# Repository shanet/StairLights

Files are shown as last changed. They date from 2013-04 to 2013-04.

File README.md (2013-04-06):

StairLights
===

### shane tully
### shanetully.com

StairLights is an Arduino-based LED stair way lighting project. It uses an Arduino, two IR transmitters, two IR recievers, and a strand of individually controllable LEDs to display light patterns on stairs when a person is walking up or down them.

Demo of it in action: http://www.youtube.com/watch?v=21KKr8hQo5A

## Parts

* Arduino Uno R3 (http://www.adafruit.com/products/50)
* Adafruit 36mm 12V LEDs (http://www.adafruit.com/products/683)
* 12V 5A power supply for the LEDs (https://www.adafruit.com/products/352)
* 2.1mm barallel plug adapter (https://www.adafruit.com/products/368)
* Two IR transmitters (https://www.sparkfun.com/products/10732)
* Two IR receivers (https://www.sparkfun.com/products/10266)
* About 150ft of 22 AWG hook-up wire (https://www.adafruit.com/products/290)

## Installation

A circuit diagram is provided as a png and a Fritzing file. Missing from the diagram is the external power supply connected to the LED strand.

Once everything is wired up, load the sketch on the Arduino like any other sketch.

## More Info

A much more detailed write-up is available on my blog at http://shanetully.com/2013/04/stairlights-an-arduino-based-led-stair-lighting-project/.

## License
Copyright (C) 2013 Shane Tully

This program is free software: you can redistribute it and/or modify
it under the terms of the GNU Lesser General Public License as published by
the Free Software Foundation, either version 3 of the License, or
(at your option) any later version.

This program is distributed in the hope that it will be useful,
but WITHOUT ANY WARRANTY; without even the implied warranty of
MERCHANTABILITY or FITNESS FOR A PARTICULAR PURPOSE.  See the
GNU Lesser General Public License for more details.

You should have received a copy of the GNU Lesser General Public License
along with this program.  If not, see <http://www.gnu.org/licenses/>.

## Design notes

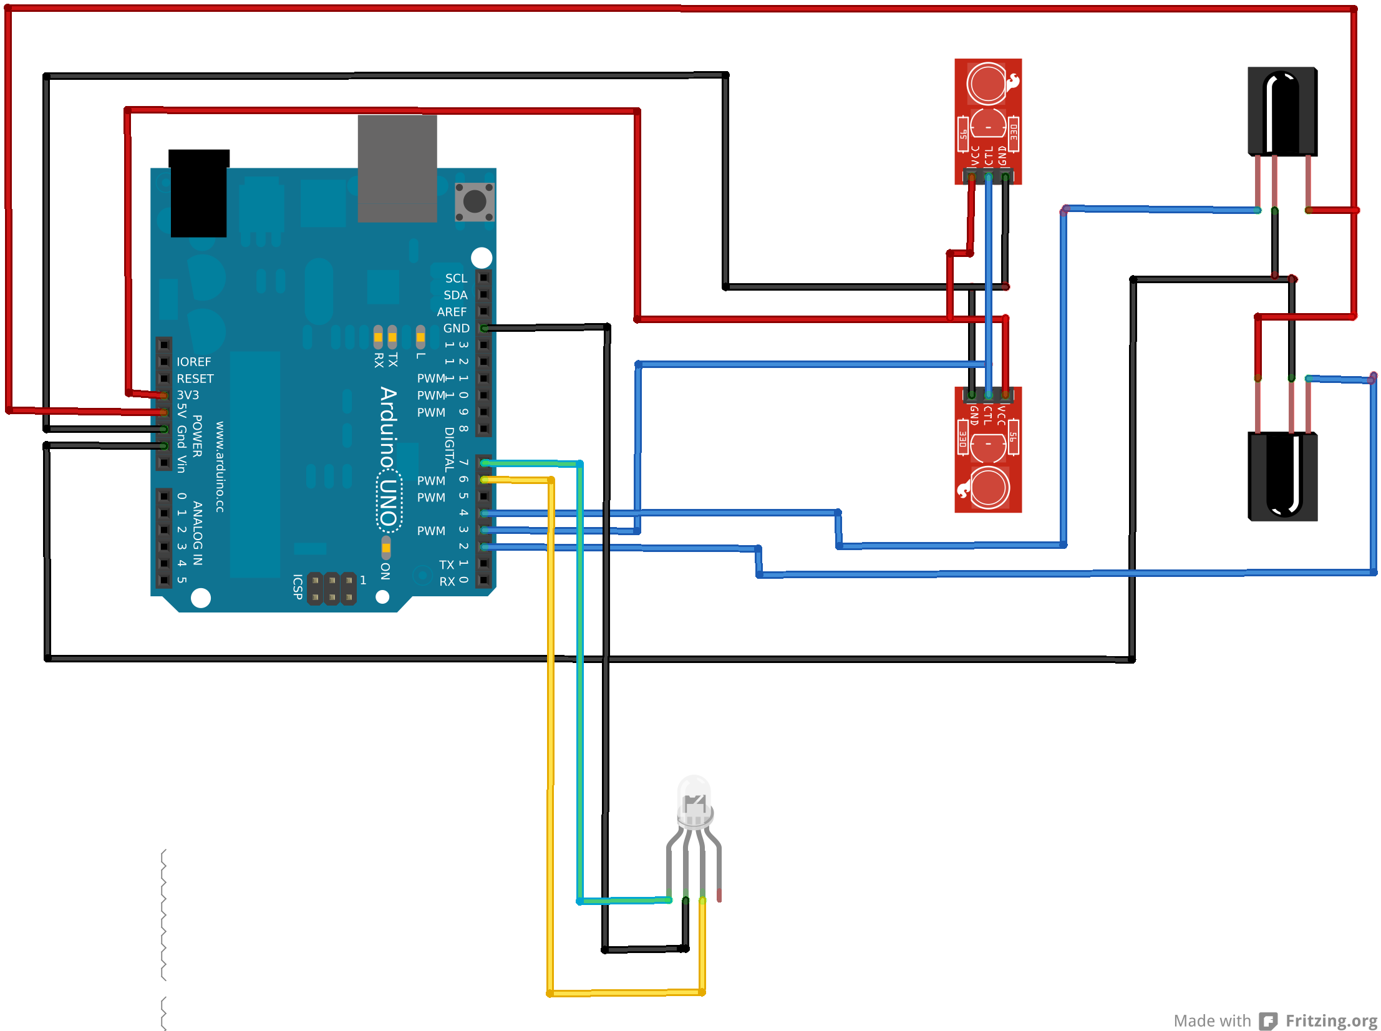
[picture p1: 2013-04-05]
stairlights_circuit_diagram.png

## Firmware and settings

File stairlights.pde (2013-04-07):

// StairLights
// shane tully (shane@shanetully.com)
// shanetully.com

// GitHub repo: https://github.com/shanet/StairLights
// Makes use of the Adafruit WS2801 LED library
// https://github.com/adafruit/Adafruit-WS2801-Library
// Code snippits taken from the Arduino IRremote library
// https://github.com/shirriff/Arduino-IRremote

// Copyright (C) 2013 Shane Tully

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
#include "SPI.h"
#include "Adafruit_WS2801.h"

#define IR_DETECT_UPSTAIRS_PIN     2
#define IR_DETECT_DOWNSTAIRS_PIN   4

#define LIGHTS_DATA_PIN  6 // Yellow wire
#define LIGHTS_CLOCK_PIN 7 // Green wire

// IR transmit frequency. You probably don't want to change this.
#define IR_KHZ     38

// Number of pixels (LEDs) in the strand
#define NUM_PIXELS 20

// Color options
#define MULTI  0
#define RED    1
#define ORANGE 2
#define YELLOW 3
#define GREEN  4
#define BLUE   5
#define PURPLE 6

// Rotation speed options
#define ROT_NONE      0
#define ROT_VERY_SLOW 1
#define ROT_SLOW      2
#define ROT_NORMAL    3
#define ROT_FAST      4
#define ROT_VERY_FAST 5

// Fade speed options
#define FADE_NONE      0
#define FADE_VERY_SLOW 1
#define FADE_SLOW      2
#define FADE_NORMAL    3
#define FADE_FAST      4
#define FADE_VERY_FAST 5

// Rotation direction options
#define ROT_CW  0
#define ROT_CCW 1

// Shadow length options
#define SDW_NONE       0
#define SDW_VERY_SMALL 1
#define SDW_SMALL      2
#define SDW_NORMAL     3
#define SDW_LONG       4
#define SDW_VERY_LONG  5

// Direction of the light pattern
#define UP   0
#define DOWN 1

#define FADE_INCOMPLETE 0
#define FADE_COMPLETE   1

// Macros for the IR transmitters. See the enable IR transmitters function.
#define TIMER_PWM_PIN        3
#define TIMER_ENABLE_PWM     (TCCR2A |= _BV(COM2B1))
#define TIMER_DISABLE_INTR   (TIMSK2 = 0)

Adafruit_WS2801 lights = Adafruit_WS2801((uint16_t)NUM_PIXELS, (uint8_t)LIGHTS_DATA_PIN, (uint8_t)LIGHTS_CLOCK_PIN, (uint8_t)WS2801_GRB);

void setup() {
   pinMode(IR_DETECT_UPSTAIRS_PIN, INPUT);
   pinMode(IR_DETECT_DOWNSTAIRS_PIN, INPUT);

   enableIrTransmitters(IR_KHZ);

   lights.begin();

   randomSeed(analogRead(0));

   // Wait a second to prevent "phantom" signals from the IR receivers on start up
   delay(1000);
}

void loop() {
   if(!digitalRead(IR_DETECT_UPSTAIRS_PIN)) {
      show_stair_lights(DOWN);
   } else if(!digitalRead(IR_DETECT_DOWNSTAIRS_PIN)) {
      show_stair_lights(UP);
   }
}


void show_stair_lights(int direction) {
   // Pick a random light pattern
   int pattern = random(0, 6);

   switch(pattern) {
      case 0:
         basic_color(direction);
         break;
      case 1:
         rainbow_fade(direction, 75);
         break;
      case 2:
         rainbow_cycle(direction, 4, 20);
         break;
      case 3:
         colorswirl(direction, 10000);
         break;
      case 4:
         trail(direction, 7, 10, 50);
         break;
      case 5:
         stack(direction, 50);
         break;
   }
}


void basic_color(int direction) {
   unsigned char red   = 0;
   unsigned char green = 0;
   unsigned char blue  = 0;

   get_random_color(&red, &green, &blue);

   int steps      = 10;
   int delay_time = 5;
   run_colors(0, red, 0, green, 0, blue, steps, direction, delay_time);

   delay(10000);

   // Fade out more slowly
   steps      = 100;
   delay_time = 40;
   run_colors(red, 0, green, 0, blue, 0, steps, direction, delay_time);
}


void run_colors(unsigned char old_red, unsigned char new_red, unsigned char old_green, unsigned char new_green, 
               unsigned char old_blue, unsigned char new_blue, int steps, int direction, int delay_time) {
   int start_pixel;
   int end_pixel;
   get_start_and_end_pixels(direction, &start_pixel, &end_pixel);

   float red_step   = (float)(new_red   - old_red)   / steps;
   float green_step = (float)(new_green - old_green) / steps;
   float blue_step  = (float)(new_blue  - old_blue)  / steps;

   if(direction == UP) start_pixel++;

   for(int i=start_pixel; (direction == UP ? i>=end_pixel : i<end_pixel); (direction == DOWN ? i+=2 : i-=2)) {
      float cur_red   = old_red;
      float cur_green = old_green;
      float cur_blue  = old_blue;

      for(int j=0; j<steps; j++) {
         cur_red   += red_step;
         cur_green += green_step;
         cur_blue  += blue_step;

         lights.setPixelColor(i, (unsigned char)cur_red, (unsigned char)cur_green, (unsigned char)cur_blue);
         lights.setPixelColor(i+1, (unsigned char)cur_red, (unsigned char)cur_green, (unsigned char)cur_blue);
         lights.show();

         delay(6);
      }

      delay(delay_time);
   }
}


void fade_colors(unsigned char old_red, unsigned char new_red, unsigned char old_green, unsigned char new_green, 
                unsigned char old_blue, unsigned char new_blue, int steps, int delay_time) {
   float red_step   = (float)(new_red   - old_red)   / steps;
   float green_step = (float)(new_green - old_green) / steps;
   float blue_step  = (float)(new_blue  - old_blue)  / steps;

   float cur_red   = old_red;
   float cur_green = old_green;
   float cur_blue  = old_blue;

   for(int i=0; i<steps; i++) {
      cur_red   += red_step;
      cur_green += green_step;
      cur_blue  += blue_step;

      for(int j=0; j<lights.numPixels(); j++) {
         lights.setPixelColor(j, (unsigned char)cur_red, (unsigned char)cur_green, (unsigned char)cur_blue);
      }

      lights.show();

      delay(delay_time);
   }
}


void rainbow_fade(int direction, int delay_time) {
   float fade_constant = 0;
   int shadow_position = get_initial_shadow_position(direction);

   int start_pixel;
   int end_pixel;
   get_start_and_end_pixels(direction, &start_pixel, &end_pixel);

   // 3 cycles of all 256 colors in the color_wheel
   for(int i=0; i<256; i++) {
      // Fade in and out on the first and last 50 cycles
      if(i < 50) {
         fade_constant += .02;
      } else if(i > 205) {
         fade_constant -= .02;
      }

      // Show the pixels one by one up/down the stairs during fading
      if(i < lights.numPixels()) {
         if(direction == UP) {
            shadow_position--;
         } else {
            shadow_position++;
         }
      }

      for(int j=start_pixel; (direction == UP ? j>=end_pixel : j<end_pixel); (direction == DOWN ? j++ : j--)) {
         float local_fade_constant = fade_constant;
         if(i < lights.numPixels() && (direction == DOWN ? j > shadow_position : j < shadow_position)) {
            local_fade_constant = 0;
         }

         lights.setPixelColor(j, color_wheel((i + j) % 255, local_fade_constant));
      }  

      lights.show();

      delay(delay_time);
   }
}


void rainbow_cycle(int direction, int num_cycles, int delay_time) {
   float fade_constant = 0;
   int shadow_position = get_initial_shadow_position(direction);

   int start_pixel;
   int end_pixel;
   get_start_and_end_pixels(direction, &start_pixel, &end_pixel);

   for(int i=0; i<256*num_cycles; i++) {
      // Fade in and out on the first and last 50 cycles
      if(i < 50) {
         fade_constant += .02;
      } else if(i > 256*num_cycles - 51) {
         fade_constant -= .02;
      }

      // Show the pixels one by one up/down the stairs during fading
      if(i < lights.numPixels()) {
         if(direction == UP) {
            shadow_position--;
         } else {
            shadow_position++;
         }
      }

      for(int j=0; j<lights.numPixels(); j++) {
         // we use each pixel as a fraction of the full 96-color color_wheel
         // (thats the i / lights.numPixels() part)
         // Then add in j which makes the colors go around per pixel
         // the % 96 is to make the color_wheel cycle around
         float local_fade_constant = fade_constant;
         if(i < lights.numPixels() && (direction == DOWN ? j > shadow_position : j < shadow_position)) {
            local_fade_constant = 0;
         }

         uint32_t color = color_wheel(((j * 256 / lights.numPixels()) + i) % 256, local_fade_constant);
         lights.setPixelColor(j, color);
      }

      lights.show();

      if(i < lights.numPixels()) {
         delay(delay_time*4);
      } else {
         delay(delay_time);
      }
   }
}


void trail(int direction, int trail_len, int cycles, int delay_time) {
   unsigned char red   = 0;
   unsigned char green = 0;
   unsigned char blue  = 0;
   get_random_color(&red, &green, &blue);

   int start_pixel;
   int end_pixel;
   get_start_and_end_pixels(direction, &start_pixel, &end_pixel);

   // Generate the constants to multiply the brightness by for the trail
   float trail_constants[trail_len];
   trail_constants[0] = (float)1/trail_len;
   for(int i=2; i<=trail_len; i++) {
      trail_constants[i-1] = trail_constants[i-2] + (float)1/trail_len;
   }

   for(int i=0; i<cycles; i++) {
      // Pick a new random color on each cycle
      unsigned char red;
      unsigned char green;
      unsigned char blue;
      get_random_color(&red, &green, &blue);

      for(int j=start_pixel; (direction == UP ? j>=end_pixel-trail_len : j<=end_pixel+trail_len); (direction == DOWN ? j++ : j--)) {
         // Set all non-trail pixels to 0
         for(int k=0; k<lights.numPixels(); k++) {
            lights.setPixelColor(k, 0, 0, 0);
         }

         // Set the trail pixels to the appropriate color
         int k = j-trail_len;
         if(direction == UP) {
            k = j+trail_len;
         }
         for(int l=0; (direction == UP ? k>j-trail_len : k<j+trail_len); (direction == UP ? k-- : k++), l++) {
            lights.setPixelColor(k, red*trail_constants[l], green*trail_constants[l], blue*trail_constants[l]);
         }

         lights.show();

         delay(delay_time);
      }
   }

   clear_lights();
}


void stack(int direction, int delay_time) {
   uint32_t color = get_random_color();

   show_stack(direction, color, delay_time);

   delay(10000);

   show_destack(direction, color, delay_time);

   clear_lights();
}


void show_stack(int direction, uint32_t color, int delay_time) {
   // The start and end pixels are reversed from the other patterns so don't use
   // the get start and end pixels function
   int start_pixel;
   int end_pixel;
   int target;
   switch(direction) {
      case UP:
         start_pixel = 0;
         end_pixel   = lights.numPixels();
         target      = lights.numPixels() - 1;
         break;
      case DOWN:
         start_pixel = lights.numPixels() - 1;
         end_pixel   = 0;
         target      = 0;
         break;
   }

   for(int i=start_pixel; (direction == UP ? i<end_pixel : i>end_pixel); (direction == DOWN ? i-=2 : i+=2)) {
      int cur_stair = lights.numPixels() - 1;
      if(direction == UP) {
         cur_stair = 0;
      }
   
      while((direction == UP ? cur_stair < target : cur_stair > target)) {
         // Turn off all pixels below the target level
         for(int j=start_pixel; (direction == UP ? j<target : j>target); (direction == DOWN ? j-- : j++)) {
            lights.setPixelColor(j, 0);
         }

         // Set the current pixel and the next pixel to the given color
         lights.setPixelColor(cur_stair, color);
         if(direction == UP) {
            lights.setPixelColor(cur_stair+1, color);
         } else {
            lights.setPixelColor(cur_stair-1, color);
         }
         lights.show();
         
         if(direction == UP) {
            cur_stair += 2;
         } else {
            cur_stair -= 2;
         }

         delay(delay_time);
      }

      if(direction == UP) {
         target -= 2;
      } else {
         target += 2;
      }
   }
}


void show_destack(int direction, uint32_t color, int delay_time) {
   int start_pixel;
   int end_pixel;
   get_start_and_end_pixels(direction, &start_pixel, &end_pixel);

   int target = lights.numPixels()-1;
   if(direction == UP) {
      target = 0;
   }

   for(int i=start_pixel; (direction == UP ? i>end_pixel : i<end_pixel); (direction == DOWN ? i+=2 : i-=2)) {
      int cur_stair = target;
   
      while((direction == UP ? cur_stair >= end_pixel : cur_stair <= end_pixel)) {
         // Turn off all pixels above the target level
         for(int j=end_pixel; (direction == UP ? j<target+2 : j>target-2); (direction == DOWN ? j-- : j++)) {
            lights.setPixelColor(j, 0);
         }

         // Set the current pixel and the next pixel to the given color
         lights.setPixelColor(cur_stair, color);
         if(direction == UP) {
            lights.setPixelColor(cur_stair+1, color);
         } else {
            lights.setPixelColor(cur_stair-1, color);
         }
         lights.show();
         
         if(direction == UP) {
            cur_stair -= 2;
         } else {
            cur_stair += 2;
         }

         delay(delay_time);
      }

      if(direction == UP) {
         target += 2;
      } else {
         target -= 2;
      }
   }
}


void colorswirl(int direction, int run_time) {
   // These are fun to play with to generate different effects
   // See the macros defined at the top of the file for options
   int color           = MULTI;
   int rotation_speed  = ROT_VERY_FAST;
   int rotation_dir    = ROT_CCW;
   int shadow_length   = SDW_VERY_SMALL;
   int fade_speed      = FADE_NONE;

   // Rotate the other way if going down the stairs
   if(direction == DOWN) {
      rotation_dir = ROT_CW;
   }

   unsigned long start_time = millis();

   // Fade in
   while(get_colorswirl_data(1, 0, color, rotation_speed, rotation_dir, shadow_length, fade_speed) != FADE_COMPLETE) {
      lights.show();
   }

   // Main loop
   // Run for the specified time
   while(start_time + run_time > millis()) {
      get_colorswirl_data(0, 0, color, rotation_speed, rotation_dir, shadow_length, fade_speed);
      lights.show();
   }

   // Fade out
   while(get_colorswirl_data(0, 1, color, rotation_speed, rotation_dir, shadow_length, fade_speed) != FADE_COMPLETE) {
      lights.show();
   }
}


int get_colorswirl_data(int fade_in, int fade_out, int color, int rotation_speed, int rotation_dir, int shadow_length, int fade_speed) {
   static float shadow_position = 0;
   static float light_position  = 0;
   static int hue               = 0;
   static float fade_constant   = 0;

   int brightness;
   unsigned char red;
   unsigned char green;
   unsigned char blue;

   shadow_position = light_position;

   for(int i=0; i<lights.numPixels(); i++) {
      get_led_color(color, &red, &green, &blue, hue);

      // Resulting hue is multiplied by brightness in the
      // range of 0 to 255 (0 = off, 255 = brightest).
      // Gamma corrrection (the 'pow' function here) adjusts
      // the brightness to be more perceptually linear.
      brightness = (shadow_length != SDW_NONE || rotation_speed != ROT_NONE) ? (int)(pow(0.5 + sin(shadow_position) * 0.5, 3.0) * 255.0) : 255;

      // If fading in or out, reduce the brightness by the fade constant
      if(fade_in || fade_out) {
         brightness *= fade_constant;
      }

      lights.setPixelColor(i, create_color((red*brightness) / 255, (green*brightness) / 255, (blue*brightness) / 255));

      // Each pixel is offset in both hue and brightness
      update_shadow_position(shadow_length, &shadow_position);
   }

   // If color is multi and fade flag was selected, do a slow fade between colors with the rot speed
   if(fade_speed != FADE_NONE && color == MULTI) {
      switch(fade_speed) {
         case FADE_VERY_SLOW:
            delay(180);
            break;
         case FADE_SLOW:
            delay(130);
            break;
         default:
         case FADE_NORMAL:
            delay(90);
            break;
         case FADE_FAST:
            delay(30);
            break;
         case FADE_VERY_FAST:
            delay(10);
            break;
      }
   }

   // Slowly rotate hue and brightness in opposite directions
   update_hue(&hue);
   update_light_position(rotation_speed, rotation_dir, &light_position);

   return update_fade_constant(fade_in, fade_out, &fade_constant);
}


void get_led_color(int color, unsigned char *r, unsigned char *g, unsigned char *b, int cur_hue) {
    unsigned char low_byte;

    switch(color) {
        case MULTI:
            // Fixed-point hue-to-RGB conversion.  'cur_hue' is an
            // integer in the range of 0 to 1535, where 0 = red,
            // 256 = yellow, 512 = green, etc.  The high byte
            // (0-5) corresponds to the sextant within the color
            // wheel, while the low byte (0-255) is the
            // fractional part between primary/secondary colors.
            low_byte = cur_hue & 255;

            switch((cur_hue >> 8) % 6) {
                case 0:
                    *r = 255;
                    *g = low_byte;
                    *b = 0;
                    break;
                case 1:
                    *r = 255 - low_byte;
                    *g = 255;
                    *b = 0;
                    break;
                case 2:
                    *r = 0;
                    *g = 255;
                    *b = low_byte;
                    break;
                case 3:
                    *r = 0;
                    *g = 255 - low_byte;
                    *b = 255;
                    break;
                case 4:
                    *r = low_byte;
                    *g = 0;
                    *b = 255;
                    break;
                case 5:
                    *r = 255;
                    *g = 0;
                    *b = 255 - low_byte;
                    break;
            }

            cur_hue += 40;
            break;
        case RED:
            *r = 255;
            *g = 0;
            *b = 0;
            break;
        case ORANGE:
            *r = 255;
            *g = 165;
            *b = 0;
            break;
        case YELLOW:
            *r = 255;
            *g = 255;
            *b = 0;
            break;
        case GREEN:
            *r = 0;
            *g = 255;
            *b = 0;
            break;
        case BLUE:
            *r = 0;
            *g = 0;
            *b = 255;
            break;
        case PURPLE:
            *r = 128;
            *g = 0;
            *b = 128;
            break;
    }
}


void update_light_position(int rotation_speed, int rotation_dir, float *light_position) {
    switch(rotation_speed) {
        case ROT_NONE:
            *light_position = 0;
            break;
        case ROT_VERY_SLOW:
            *light_position += (rotation_dir == ROT_CW) ? -.007 : .007;
            break;
        case ROT_SLOW:
            *light_position += (rotation_dir == ROT_CW) ? -.015 : .015;
            break;
        case ROT_NORMAL:
        default:
            *light_position += (rotation_dir == ROT_CW) ? -.03 : .03;
            break;
        case ROT_FAST:
            *light_position += (rotation_dir == ROT_CW) ? -.045 : .045;
            break;
        case ROT_VERY_FAST:
            *light_position += (rotation_dir == ROT_CW) ? -.07 : .07;
            break;
    }
}


void update_shadow_position(int shadow_length, float *shadow_position) {
    switch(shadow_length) {
        case SDW_NONE:
            *shadow_position += 0;
            break;
        case SDW_VERY_SMALL:
            *shadow_position += 0.9;
            break;
        case SDW_SMALL:
            *shadow_position += 0.6;
            break;
        case SDW_NORMAL:
        default:
            *shadow_position += 0.3;
            break;
        case SDW_LONG:
            *shadow_position += 0.2;
            break;
        case SDW_VERY_LONG:
            *shadow_position += 0.08;
            break;
    }
}


void update_hue(int *cur_hue) {
    static int hue = 0;
    *cur_hue = hue = (hue + 5) % 1536;
}


int update_fade_constant(int fade_in, int fade_out, float *fade_constant) {
   #define FADE_STEP .0025;

   // If fading in, add the fade step to the fade constant
   // If the constant is 1, we're finished fading in
   if(fade_in && *fade_constant < 1) {
      *fade_constant += FADE_STEP;

      if(*fade_constant >= 1) {
         return FADE_COMPLETE;
      }
   // If fading out, subtract the fade step to the fade constant
   // If the constant is 0, we're finished fading out
   } else if(fade_out && *fade_constant > 0) {
      *fade_constant -= FADE_STEP;

      if(*fade_constant <= 0) {
         return FADE_COMPLETE;
      }
   } else {
      return FADE_INCOMPLETE;
   }
}


void get_random_color(unsigned char *red, unsigned char *green, unsigned char *blue) {
   int color = random(RED, PURPLE+1);

   *red   = 0;
   *green = 0;
   *blue  = 0;

   switch(color) {
      case RED:
         *red = 255;
         break;
      case ORANGE:
         *red   = 255;
         *green = 165;
         break;
      case YELLOW:
         *red   = 255;
         *green = 255;
         break;
      case GREEN:
         *green = 255;
         break;
      case BLUE:
         *blue = 255;
         break;
      case PURPLE:
         *red  = 128;
         *blue = 128;
         break;
   }
}


uint32_t get_random_color(void) {
   unsigned char red   = 0;
   unsigned char green = 0;
   unsigned char blue  = 0;

   get_random_color(&red, &green, &blue);
   return create_color(red, green, blue);
}


void clear_lights(void) {
   // Turn off all lights
   for(int i=0; i<lights.numPixels(); i++) {
      lights.setPixelColor(i, 0);
      lights.show();
   }
}


uint32_t create_color(unsigned char red, unsigned char green, unsigned char blue) {
   // Create a 24 bit color value from R, G, B values
   // Bits 24-16: red
   // Bits 15-8:  green
   // Bits 7-0:   blue
   uint32_t color;

   color = red;
   color <<= 8;

   color |= green;
   color <<= 8;
   
   color |= blue;

   return color;
}


int get_initial_shadow_position(int direction) {
   // For fades with a shadow, the shadow should grow from the beginning or end
   // of the LEDs depending on direction
   switch(direction) {
      case UP:
         return lights.numPixels();
      case DOWN:
         return 0;
   }
}
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

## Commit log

2013-04-05 fixed infinite loop in colorswirl pattern
    [stairlights.pde]
2013-04-05 added circuit diagrams
    [stairlights_circuit_diagram.fzz]
2013-04-07 added stack pattern and fixed number of LEDs
    [stairlights.pde]
